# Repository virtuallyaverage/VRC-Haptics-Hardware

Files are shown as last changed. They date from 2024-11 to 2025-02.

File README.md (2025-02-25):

# Development moved to: https://github.com/VRC-Haptics/VRCH-Hardware

Hardware implementation for vrc haptics project. See: Firmware: [VRC-Haptics-Firmware](https://github.com/virtuallyaverage/VRC-Haptics-Firmware), Server: [VRC-Haptics-Hardware](https://github.com/virtuallyaverage/VRC-Haptics-Host)

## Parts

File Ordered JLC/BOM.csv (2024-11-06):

Comment | Designator | Footprint | JLCPCB Part#(optional)
1kΩ | R9,R8 | R_0805_2012Metric | C17513
10kΩ | R5,R4,R7,R6,R2,R1,R3 | R_0805_2012Metric | C17414
0.1uF | C1,C2 | C_0805_2012Metric | C49678
PCA9685PW | U3 | TSSOP-28_4.4x9.7mm_P0.65mm | C92206

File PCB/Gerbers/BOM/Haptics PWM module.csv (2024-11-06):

Id | Designator | Footprint | Quantity | Designation | Supplier and ref
1 | R6,R5,R4,R7,R3,R2,R1 | R_0805_2012Metric | 7 | 10k
2 | U3 | TSSOP-28_4.4x9.7mm_P0.65mm | 1 | PCA9685PW
3 | U2,U1 | DIP-18_W7.62mm | 2 | ULN2803A
4 | R9,R8 | R_0805_2012Metric | 2 | 1k
5 | C2,C1 | C_0805_2012Metric | 2 | 0.1uF

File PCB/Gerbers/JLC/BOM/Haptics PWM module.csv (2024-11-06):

Id | Designator | Footprint | Quantity | Designation | Supplier and ref
1 | U1,U2 | SOIC-18W_7.5x11.6mm_P1.27mm | 2 | ULN2803A
2 | R9,R8 | R_0805_2012Metric | 2 | 1k
3 | R5,R4,R7,R6,R2,R1,R3 | R_0805_2012Metric | 7 | 10k
4 | C1,C2 | C_0805_2012Metric | 2 | 0.1uF
5 | U3 | TSSOP-28_4.4x9.7mm_P0.65mm | 1 | PCA9685PW

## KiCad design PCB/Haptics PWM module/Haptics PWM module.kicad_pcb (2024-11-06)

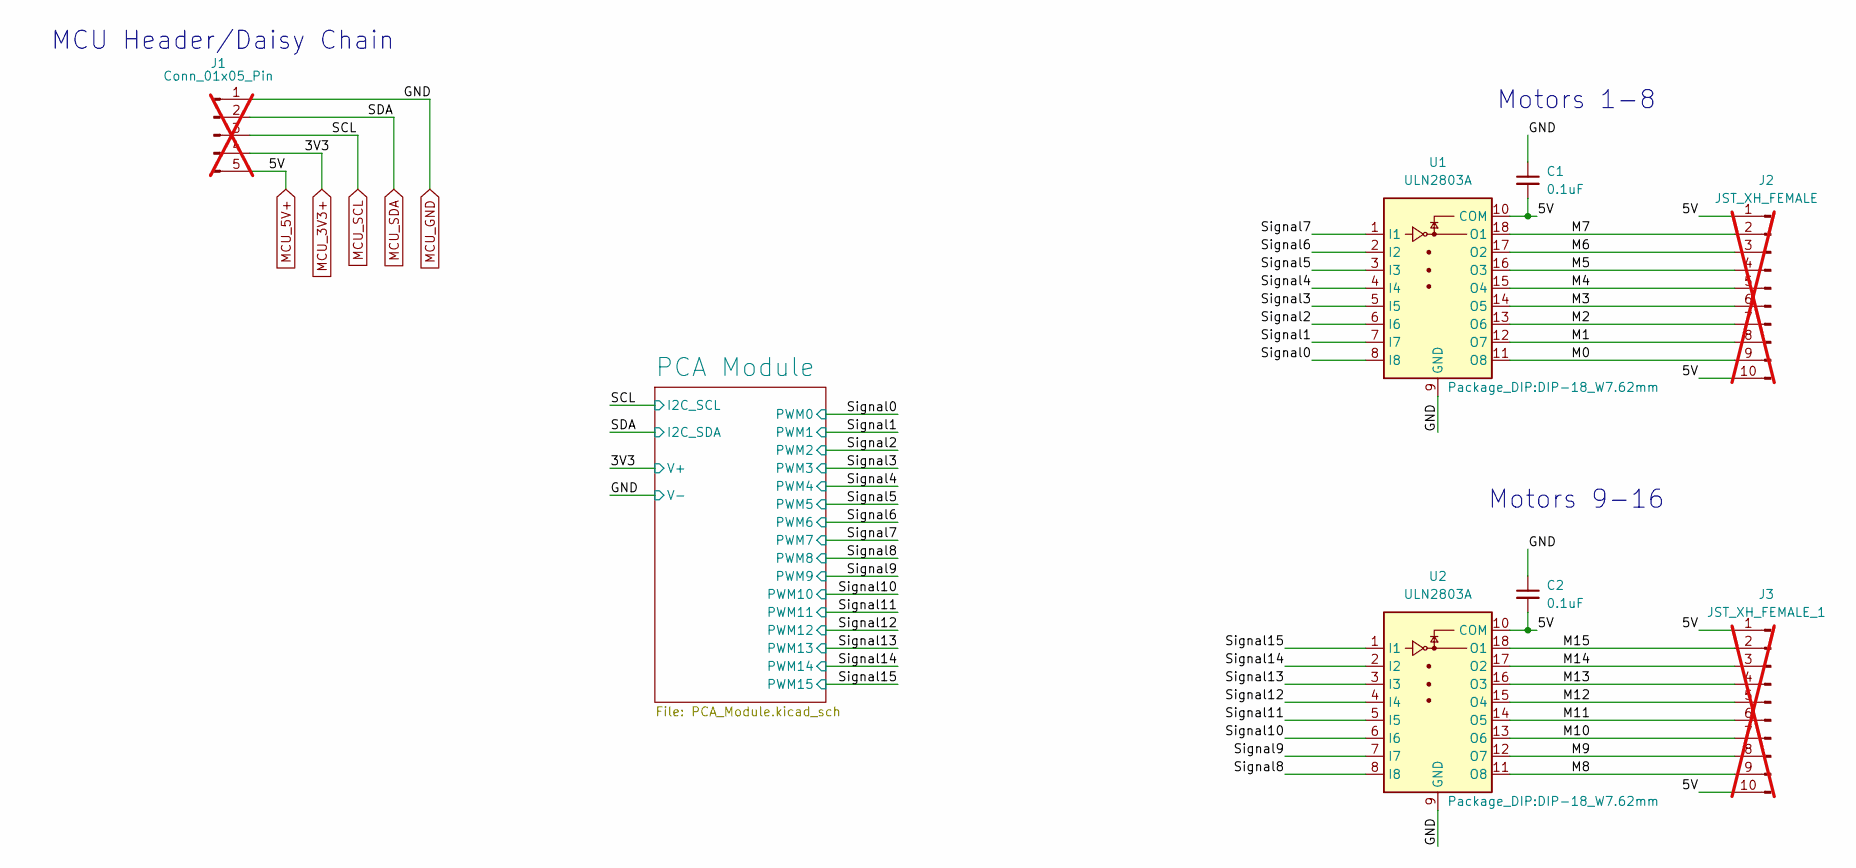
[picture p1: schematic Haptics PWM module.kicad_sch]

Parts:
C1, C2: 0.1uF; C_0805_2012Metric
J1: Conn_01x05_Pin; PinHeader_1x05_P2.54mm_Vertical; not fitted
J2: JST_XH_FEMALE; PinHeader_1x10_P2.00mm_Vertical; not fitted
J3: JST_XH_FEMALE_1; PinHeader_1x10_P2.00mm_Vertical; not fitted
U1, U2: ULN2803A; DIP-18_W7.62mm

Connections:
/M0: J2.9, U1.11 (O8)
/M1: J2.8, U1.12 (O7)
/M2: J2.7, U1.13 (O6)
/M3: J2.6, U1.14 (O5)
/M4: J2.5, U1.15 (O4)
/M5: J2.4, U1.16 (O3)
/M6: J2.3, U1.17 (O2)
/M7: J2.2, U1.18 (O1)
/M8: J3.9, U2.11 (O8)
/M9: J3.8, U2.12 (O7)
/M10: J3.7, U2.13 (O6)
/M11: J3.6, U2.14 (O5)
/M12: J3.5, U2.15 (O4)
/M13: J3.4, U2.16 (O3)
/M14: J3.3, U2.17 (O2)
/M15: J3.2, U2.18 (O1)
/Signal0: U1.8 (I8); also elsewhere on the board
/Signal1: U1.7 (I7); also elsewhere on the board
/Signal2: U1.6 (I6); also elsewhere on the board
/Signal3: U1.5 (I5); also elsewhere on the board
/Signal4: U1.4 (I4); also elsewhere on the board
/Signal5: U1.3 (I3); also elsewhere on the board
/Signal6: U1.2 (I2); also elsewhere on the board
/Signal7: U1.1 (I1); also elsewhere on the board
/Signal8: U2.8 (I8); also elsewhere on the board
/Signal9: U2.7 (I7); also elsewhere on the board
/Signal10: U2.6 (I6); also elsewhere on the board
/Signal11: U2.5 (I5); also elsewhere on the board
/Signal12: U2.4 (I4); also elsewhere on the board
/Signal13: U2.3 (I3); also elsewhere on the board
/Signal14: U2.2 (I2); also elsewhere on the board
/Signal15: U2.1 (I1); also elsewhere on the board
MCU_3V3+: J1.4; also elsewhere on the board
MCU_5V+: C1.2, C2.2, J1.5, J2.1, J2.10, J3.1, J3.10, U1.10 (COM), U2.10 (COM)
MCU_GND: C1.1, C2.1, J1.1, U1.9 (GND), U2.9 (GND); also elsewhere on the board
MCU_SCL: J1.3; also elsewhere on the board
MCU_SDA: J1.2; also elsewhere on the board

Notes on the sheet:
Motors 1-8
Motors 9-16
MCU Header/Daisy Chain

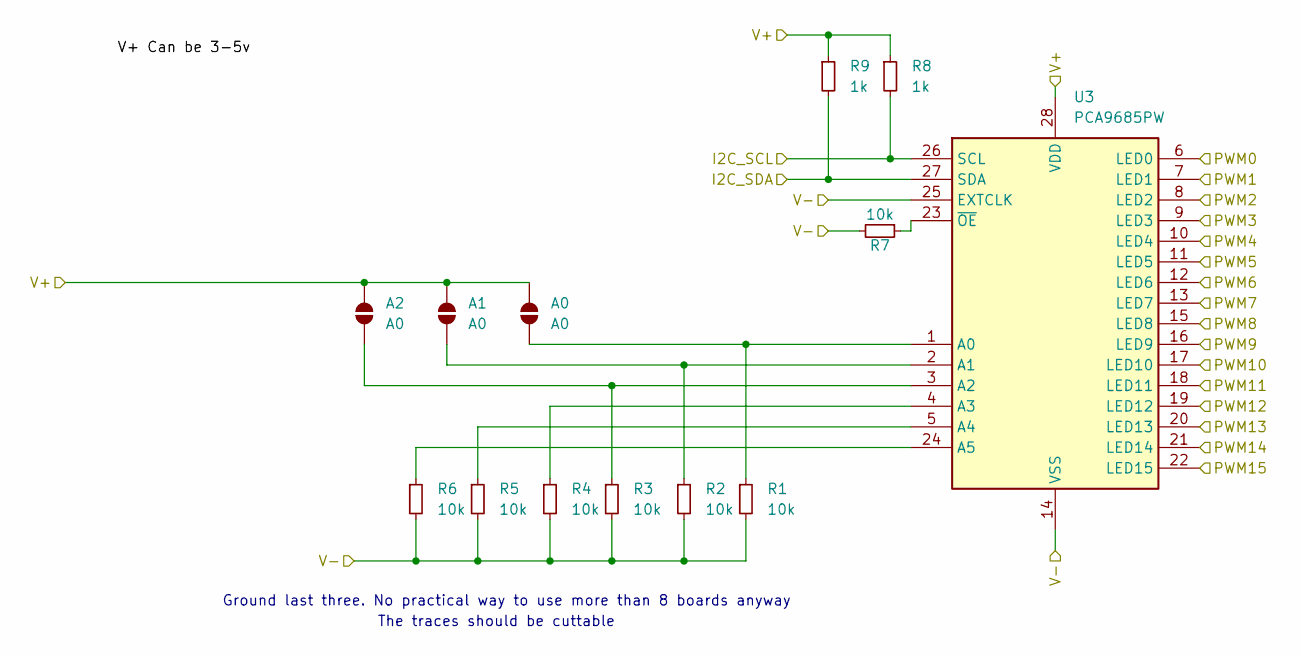
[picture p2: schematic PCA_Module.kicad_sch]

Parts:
A0, A1, A2: A0; SolderJumper-2_P1.3mm_Open_TrianglePad1.0x1.5mm
R1, R2, R3, R4, R5, R6, R7: 10k; R_0805_2012Metric
R8, R9: 1k; R_0805_2012Metric
U3: PCA9685PW; TSSOP-28_4.4x9.7mm_P0.65mm

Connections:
/Signal0: U3.6 (LED0); also elsewhere on the board
/Signal1: U3.7 (LED1); also elsewhere on the board
/Signal2: U3.8 (LED2); also elsewhere on the board
/Signal3: U3.9 (LED3); also elsewhere on the board
/Signal4: U3.10 (LED4); also elsewhere on the board
/Signal5: U3.11 (LED5); also elsewhere on the board
/Signal6: U3.12 (LED6); also elsewhere on the board
/Signal7: U3.13 (LED7); also elsewhere on the board
/Signal8: U3.15 (LED8); also elsewhere on the board
/Signal9: U3.16 (LED9); also elsewhere on the board
/Signal10: U3.17 (LED10); also elsewhere on the board
/Signal11: U3.18 (LED11); also elsewhere on the board
/Signal12: U3.19 (LED12); also elsewhere on the board
/Signal13: U3.20 (LED13); also elsewhere on the board
/Signal14: U3.21 (LED14); also elsewhere on the board
/Signal15: U3.22 (LED15); also elsewhere on the board
MCU_3V3+: A0.2 (B), A1.2 (B), A2.2 (B), R8.1, R9.1, U3.28 (VDD); also elsewhere on the board
MCU_GND: R1.2, R2.2, R3.2, R4.2, R5.2, R6.2, R7.2, U3.14 (VSS), U3.25 (EXTCLK); also elsewhere on the board
MCU_SCL: R8.2, U3.26 (SCL); also elsewhere on the board
MCU_SDA: R9.2, U3.27 (SDA); also elsewhere on the board
unnamed: A0.1 (A), R1.1, U3.1 (A0)
unnamed: A1.1 (A), R2.1, U3.2 (A1)
unnamed: A2.1 (A), R3.1, U3.3 (A2)
unnamed: R4.1, U3.4 (A3)
unnamed: R5.1, U3.5 (A4)
unnamed: R6.1, U3.24 (A5)
unnamed: R7.1, U3.23 (~OE)

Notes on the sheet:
The traces should be cuttable
Ground last three. No practical way to use more than 8 boards anyway

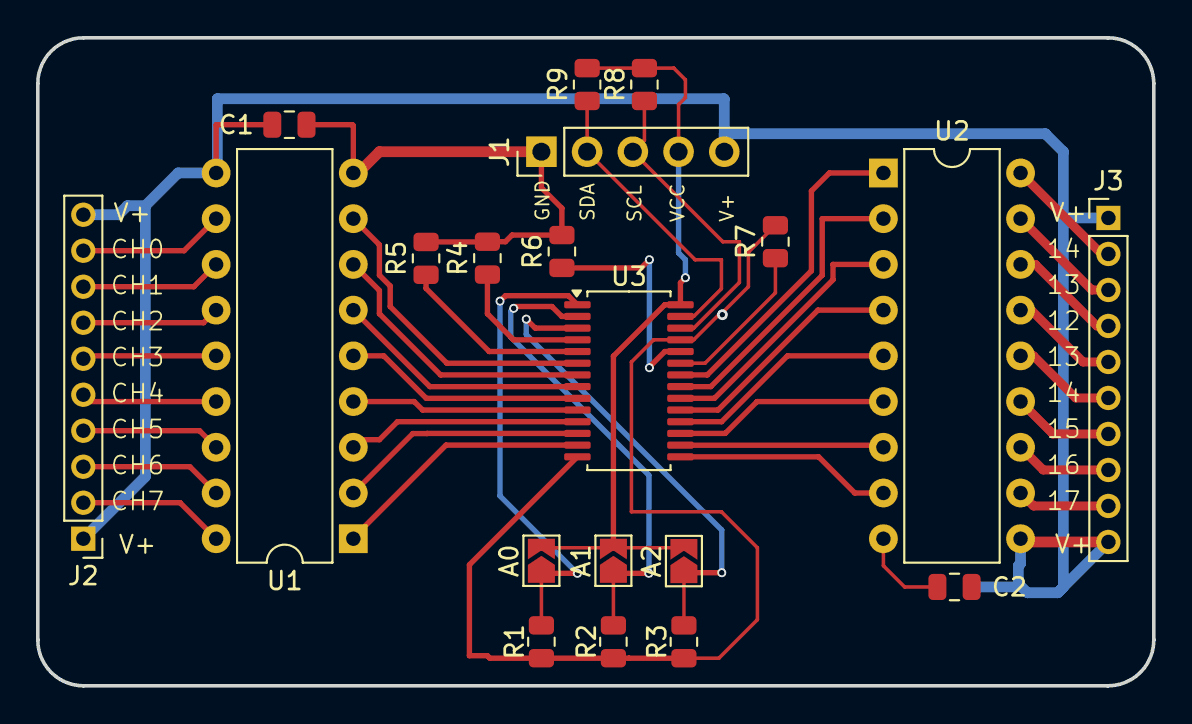
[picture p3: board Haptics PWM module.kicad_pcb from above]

Board: 2 copper layers, 62.0 x 36.0 mm, 20 parts (0 on the bottom side), 44 nets.
